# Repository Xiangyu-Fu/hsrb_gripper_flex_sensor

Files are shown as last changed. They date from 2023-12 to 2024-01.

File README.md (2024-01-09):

# HSRB gripper flex sensor repo

## Wire connection
```
Green --> 21
Yellow --> 22
Black --> GND
Brown --> 3V3
```

### Note
Don't put the two sensors too close to each other, otherwise the readings will be affected.

## HSRB

I put the `uart_reader.py` in` /home/hsr-hmi/ros/workspaces/hsrb_ws/src/ros_skin_node/scripts/uart_reader.py`.

How to run
```bash
cd ros/workspaces/hsrb_ws
source devel/setup.bash
rosrun ros_skin_node uart_reader.py
```

In local computer
```
hsrb_mode
rostopic echo /spike_counts
```

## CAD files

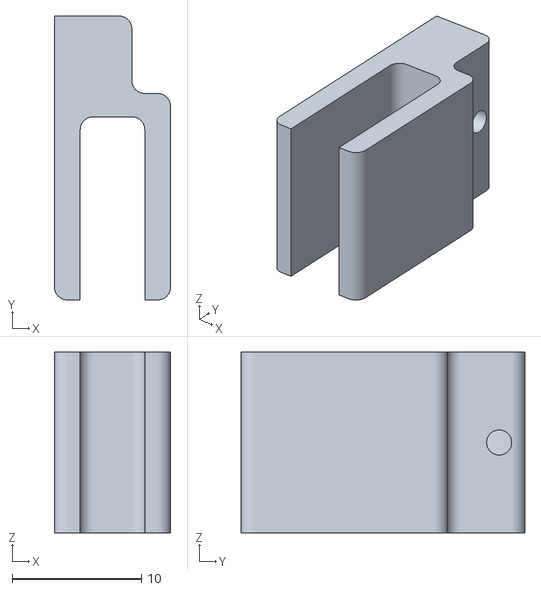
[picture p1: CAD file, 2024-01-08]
models/STL/gripper_clamp_v2.STL
9.00 x 22.0 x 14.0

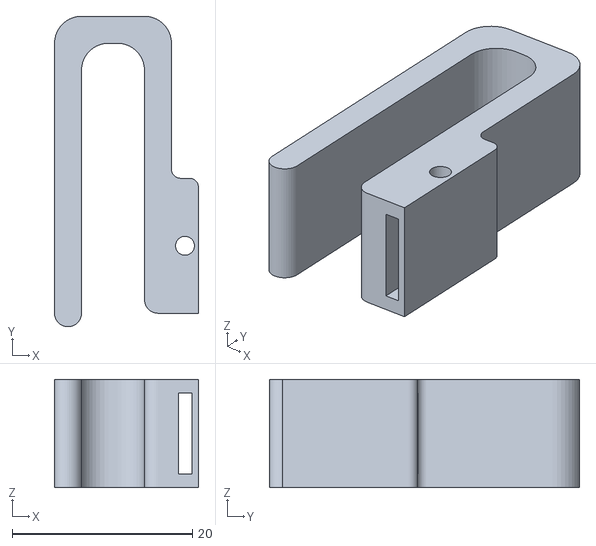
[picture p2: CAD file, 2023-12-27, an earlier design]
models/STL/gripper_clamp_v1.STL
16.0 x 34.5 x 12.0

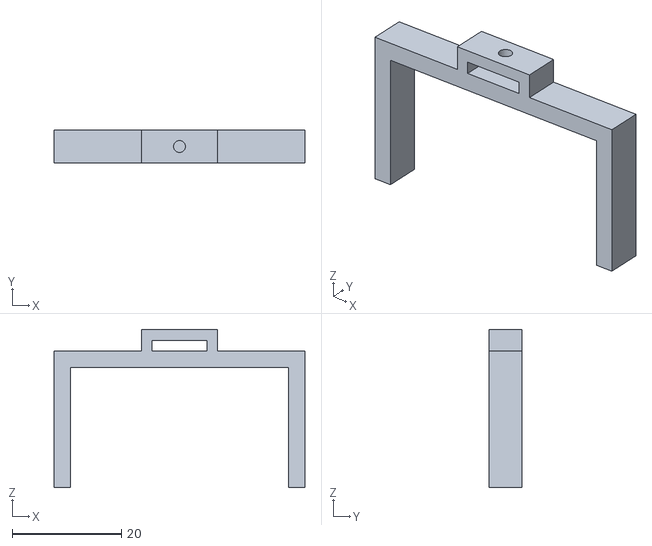
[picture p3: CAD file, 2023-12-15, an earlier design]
models/STL/gripper_clamp_v0.STL
46.0 x 6.00 x 29.0

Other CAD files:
models/SW/gripper_clamp_v2.SLDPRT
models/SW/gripper_clamp_v1.SLDPRT
models/SW/gripper_clamp_v0.SLDPRT

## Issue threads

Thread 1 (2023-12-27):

Data Reading Bug

Xiangyu-Fu, 2023-12-27:
It cannot read the data from two sensors simultaneously and needs to find out why. Possibly because of the Hardware connection or the Software setting, the code is working for one sensor.

Xiangyu-Fu, 2023-12-27:
In commit f4c5539, I have already fixed this bug. It is for two reasons:
1. The two sensors have not been correctly calibrated.
2. The two sensors were too close to each other which may affect the data reading.

Closed 2023-12-27.

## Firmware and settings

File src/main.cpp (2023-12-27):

/*
 * Project: HSRB Gripper with flex sensors
 * Description: This code is used to read the flex sensors and send the data to the computer
 * Author: Xiangyu Fu
 * Date: 2023-12-27
 */

#if defined(ARDUINO_SAMD_ZERO) && defined(SERIAL_PORT_USBVIRTUAL)
  // Required for Serial on Zero based boards
  #define Serial SERIAL_PORT_USBVIRTUAL
#endif

#include "Arduino.h"
#include "bsp_ads.h"
#include "Wire.h"

ADS ads_1; 
ADS ads_2;

const byte dataReadyPin = 4; //This can be any pin, but avoid pin 2. See: https://learn.sparkfun.com/tutorials/sparkfun-pro-nrf52840-mini-hookup-guide
// "Because pin 2's state at reset is sampled by the bootloader, be careful using it with any component that may pull the pin low on startup."

long lastTime;

unsigned long samples_1 = 0; //Allows us to calculate the actual read rate in Hz
unsigned long samples_2 = 0; //Allows us to calculate the actual read rate in Hz
byte deviceType;           //Keeps track of if this sensor is a one axis of two axis sensor

// Izhikevich model parameters
double a = 0.02;
double b = 0.2;
double c = -65;
double d = 6;
double v_1 = -70; // Initial membrane potential
double u_1 = b * v_1; // Initial recovery variable
double v_2 = -70; // Initial membrane potential
double u_2 = b * v_2; // Initial recovery variable


void calibrate(ADS myFlexSensor);

void setup()
{
  // pinMode(dataReadyPin, INPUT);

  Serial.begin(115200);
  while (!Serial)
    ;
  Serial.println(F("SparkFun Displacement Sensor Example"));

  Wire.begin();
  Wire.setClock(400000); //Note this sensor supports 400kHz I2C

  if (ads_1.begin(33) == false)
  {
    Serial.println(F("No sensor detected. Check wiring. Freezing..."));
    while (1)
      ;
  }

  Serial.println(F("Sensor 1 detected!"));

  if (ads_2.begin(34) == false)
  {
    Serial.println(F("No sensor detected. Check wiring. Freezing..."));
    while (1)
      ;
  }
  Serial.println(F("Sensor 2 detected!"));
  ads_1.enableStretching(true); // Enable receiving stretching data
  ads_2.enableStretching(true); // Enable receiving stretching data
}

void loop()
{

  if (ads_1.available() == true  && ads_2.available() == true)
  {    
    double X_1 = ads_1.getX();
    double I_1 = abs(X_1);

    v_1 += 0.04 * v_1 * v_1 + 5 * v_1 + 140 - u_1 + I_1;
    u_1 += a * (b * v_1 - u_1);

    // Check for ads_1 spike condition
    if (v_1 >= 30) {
      v_1 = c;
      u_1 += d;
      Serial.println("Neuron 1 spike");
    }

    double X_2 = ads_2.getX();
    double I_2 = abs(X_2);

    v_2 += 0.04 * v_2 * v_2 + 5 * v_2 + 140 - u_2 + I_2;
    u_2 += a * (b * v_2 - u_2);

    // Check for ads_2 spike condition
    if (v_2 >= 30) {
      v_2 = c;
      u_2 += d;
      Serial.println("Neuron 2 spike");
    }
  }

    if (Serial.available())
  {
    byte incoming = Serial.read();

    if (incoming == 'a')
    {
      calibrate(ads_1);
    }
      
    else if (incoming == 'b')
    {
      calibrate(ads_2);
    }

    else
    {
      Serial.println("press a or b to calibrate \n OR Reset the Arduino to back to read the sensor");
    }
  }

}

void calibrate(ADS myFlexSensor)
{
  Serial.println(F("Calibration routine"));

  while (Serial.available() > 0)
    Serial.read(); //Flush all characters
  Serial.println(F("Press a key when the sensor is flat and straight on a table"));
  while (Serial.available() == 0)
  {
    myFlexSensor.available();
    delay(10); //Wait for user to press character
  }

  myFlexSensor.calibrateZero(); //Call when sensor is straight on both axis

  while (Serial.available() > 0)
    Serial.read(); //Flush all characters
  Serial.println(F("Good. Now press a key when the sensor is flat on table but bent at 90 degrees (along X axis)."));
  while (Serial.available() == 0)
  {
    myFlexSensor.available();
    delay(10); //Wait for user to press character
  }

  myFlexSensor.calibrateX(); //Call when sensor is straight on Y axis and 90 degrees on X axis

  Serial.println(F("Calibration complete."));
}

// void updateIzhikevichModel(double sensorValue, int sensorNumber) {
//   // Convert sensor value to current input for the Izhikevich model
//   double I = abs(sensorValue);

//   // Update the Izhikevich model
//   v += 0.04 * v * v + 5 * v + 140 - u + I;
//   u += a * (b * v - u);

//   // Check for spike condition
//   if (v >= 30) {
//     v = c;
//     u += d;
//     Serial.print("Neuron ");
//     Serial.print(sensorNumber);
//     Serial.println(" spike!");
//   }

//   bool __verbose = false;

//   if (__verbose){
//     // Output sensor value and model variables
//     Serial.print(samples_1 / (millis() / 1000.0), 2);
//     Serial.print("Hz, Sensor: ");
//     Serial.print(sensorValue);
//     Serial.print(", Membrane Potential: ");
//     Serial.print(v);
//     Serial.print(", Recovery Variable: ");
//     Serial.println(u);

//   }
// }

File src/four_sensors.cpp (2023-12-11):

#if 0 //For Backup Purpose Only
#include <Wire.h>
#include "bsp_ads.h" // Click here to get the library: http://librarymanager/All#SparkFun_Displacement_Sensor

ADS ads_ics_1; //Create object of the ADS class
ADS ads_ics_2; //Create object of the ADS class
ADS ads_ics_3; //Create object of the ADS class
ADS ads_ics_4; //Create object of the ADS class

void setup()
{
    Serial.begin(115200);
    while (!Serial);
    Serial.println(F("SparkFun Displacement Sensor Example"));

    Wire.begin();

    //Setup first sensor - look for it at the default address of 0x21 = 33
    if (ads_ics_1.begin(33) == false)
    {
        Serial.println(F("First sensor not detected. Check wiring. Freezing..."));
        while (1);
    }

    //Setup second sensor - look for it at the I2C address of 34.
    if (ads_ics_2.begin(34) == false)
    {
        Serial.println(F("Second sensor not detected. Check wiring. Freezing..."));
        while (1);
    }

    //Setup third sensor - look for it at the I2C address of 35.
    if (ads_ics_3.begin(35) == false)
    {
        Serial.println(F("Third sensor not detected. Check wiring. Freezing..."));
        while (1);
    }

    //Setup fourth sensor - look for it at the I2C address of 36.
    if (ads_ics_4.begin(36) == false)
    {
        Serial.println(F("Fourth sensor not detected. Check wiring. Freezing..."));
        while (1);
    }
}

void loop()
{
  if (ads_ics_1.available() == true && ads_ics_2.available() == true)
  {
    Serial.print(" 1,");
    Serial.print(ads_ics_1.getX());
    Serial.print(",");
    Serial.print(ads_ics_1.getY()); // ? may be 1-axis sensor does not have Y
    Serial.print(",");
    Serial.print(ads_ics_1.getStretchingData());
    Serial.print(" 2,");
    Serial.print(ads_ics_2.getX());
    Serial.print(",");
    Serial.print(ads_ics_2.getY());
    Serial.print(",");
    Serial.print(ads_ics_2.getStretchingData());
    Serial.print(" 3,");
    Serial.print(ads_ics_3.getX());
    Serial.print(",");
    Serial.print(ads_ics_3.getY());
    Serial.print(",");
    Serial.print(ads_ics_3.getStretchingData());
    Serial.print(" 4,");
    Serial.print(ads_ics_4.getX());
    Serial.print(",");
    Serial.print(ads_ics_4.getY());
    Serial.print(",");
    Serial.print(ads_ics_4.getStretchingData());
    Serial.println();

  }
  delay(10);
}
#endif

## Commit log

2023-12-15 add izhikevich model here
    [gripper_clamp_v0.SLDPRT, gripper_clamp_v0.STL]
2023-12-15 update support for two sensors
2023-12-27 update uart reader and models
    [gripper_clamp_v1.SLDPRT, gripper_clamp_v1.STL]
2023-12-27 update code with bugs, now it cannot read the correct value from the two sensors simultaneously, need to find out why
    [main.cpp, uart_reader.py]
2023-12-27 fix bug in data reading
    [main.cpp, uart_reader.py]
2024-01-08 auto commit at 20240108225552
    [gripper_clamp_v2.SLDPRT, gripper_clamp_v2.STL]
